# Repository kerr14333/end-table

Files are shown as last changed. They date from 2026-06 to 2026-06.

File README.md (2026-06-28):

# Cherry X-Leg End Table

A custom solid-cherry end table, designed parametrically in FreeCAD to sit beside
the leather armchair in `reference/chair.jpeg`.

**Overall: 20" L × 8¼" W × 24" H** — a thin floating top with a chamfered
underside edge over two crossed (X) tapered legs joined by half-laps, tied
together at the bottom by a central stretcher and at the top by two cleats (which
also attach the top with figure-8 fasteners for wood movement). Full dimensions and the build sequence are in
[`docs/plans.html`](docs/plans.html); the design brief is in
[`docs/END_TABLE_SPECS.md`](docs/END_TABLE_SPECS.md).

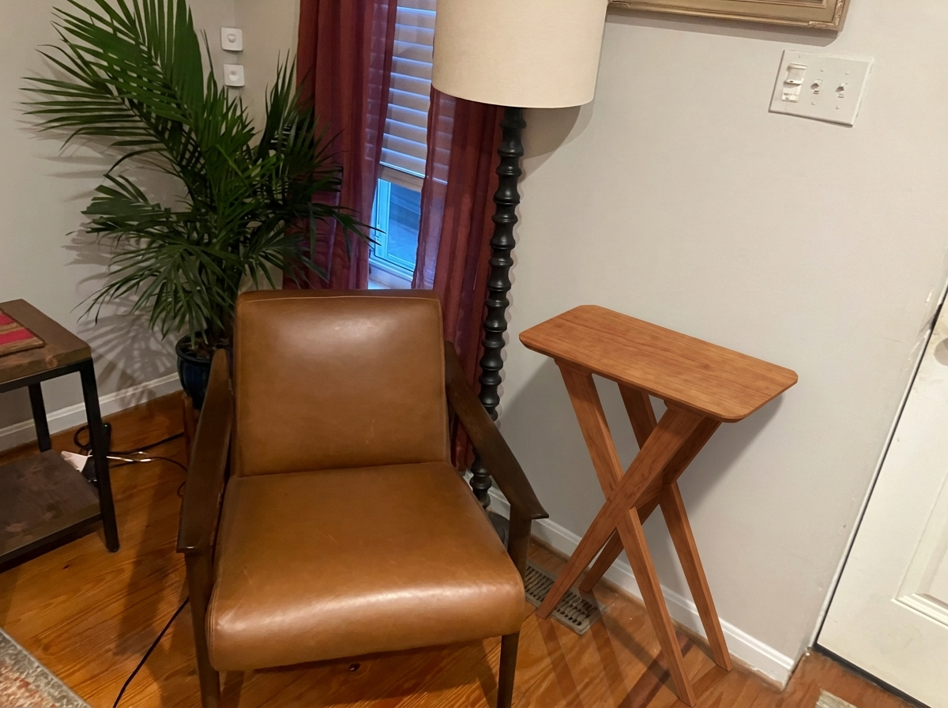
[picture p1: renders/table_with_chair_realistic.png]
Table beside the chair


## Project layout

```
end_table/
├── CLAUDE.md                 project instructions (build commands, layout)
├── README.md                 this file
├── docs/
│   ├── END_TABLE_SPECS.md    design brief / locked dimensions
│   ├── plans.html            printable build plans (cut list, joinery, steps)
│   └── diagrams/             generated SVG shop drawings (embedded in plans.html)
├── scripts/
│   ├── build_end_table.py    parametric model generator (FreeCAD)
│   ├── preview_end_table.py  orthographic CAD preview (matplotlib)
│   ├── draw_diagrams.py      dimensioned shop drawings (matplotlib → docs/diagrams)
│   └── gemini_render.py      photoreal render beside the chair (Gemini, on request)
├── model/                    generated CAD: end_table.FCStd (+ .stl mesh)
├── renders/                  generated images (previews + composite)
└── reference/                input assets: chair.jpeg
```

## Building the model

All commands run from the project root.

**1. Generate the CAD model** (writes `model/end_table.FCStd` + `.stl`):
```
"C:\Program Files\FreeCAD 1.1\bin\freecadcmd.exe" scripts\build_end_table.py
```
Edit the parameter block at the top of `scripts/build_end_table.py` to change any
dimension, then re-run.

**2. Render the CAD preview** (writes `renders/end_table_preview.png`):
```
python scripts\preview_end_table.py
```

**3. Generate the shop drawings** (writes dimensioned SVGs to `docs/diagrams/`,
embedded in `plans.html`):
```
python scripts\draw_diagrams.py
```

**4. Photoreal render beside the chair** (optional; writes
`renders/table_with_chair_realistic.png`):
```
python scripts\gemini_render.py
```
Requires `GEMINI_API_KEY` in the environment, `pip install google-genai`, and
billing enabled on the Google project.

## Requirements

- FreeCAD 1.1 (headless `freecadcmd`)
- Python 3 with `numpy`, `matplotlib`, `Pillow` (and `google-genai` for the
  Gemini render)

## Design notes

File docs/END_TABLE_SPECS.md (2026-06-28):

# End Table Spec

Material: 3/4" milled cherry. Build modeled in FreeCAD (see `build_end_table.py`).
Style: sleek modern / mid-century, to sit next to the chair in `images/chair.jpeg`
(warm wood, tapered splayed legs, eased edges, natural oil finish).

## Locked dimensions
* Overall: 24" tall.
* Top: 20" long x 8 1/4" wide x 3/4" thick. Width is fixed; length may be adjusted.
  * Corners rounded, 1 1/8" radius.
  * Underside perimeter: 45-deg routed chamfer 9/16" wide, leaving a 3/16" edge (reads thin / floats).
  * Top edge crisped with a 1/32" micro-bevel.
* Legs: two crossed (X) frames, 3/4" stock, tapered 2 1/2" wide at top to 1" at the foot.
  * Leg lean 30 deg from vertical (60 deg crossing angle). Chosen so the leg-end
    cuts (30 deg off square) and the half-lap nibble (90 - 2x30 = 30 deg off
    square) both fall on a positive stop of the miter gauge (POWERTEC 71391:
    every 5 deg to 60, plus 22.5). Tapers are done on a jig, so unconstrained.
  * Joined at each crossing with a half-lap, 3/8" deep.
  * Feet splayed past the tips (~15 7/8" stance) for stability; legs centered under the top.
  * End overhang ~4 1/2", side overhang ~1" (legs set wide for side-to-side stability).
* One central stretcher ties the two frames together at the crossing. It is glued
  and dowelled into each frame's inner face — two 3/8" dowels per end (its end
  grain needs the dowels; glue alone there is weak).
* Two cleats (~7 x 3 5/8 x 3/4) under the ends of the top: sized and centered on
  the angled leg-tip footprint so each leg seats squarely (the trimmed tips land
  slightly inboard of the leg's nominal tip). The two long bottom edges are eased
  with a 1/4" 45-deg bevel so the cleats read lighter (ends left square, where the
  leg tips bear). The leg tips bear on them, they tie the two frames together at
  the top, and the top fastens to them with figure-8 (desktop) fasteners — two per
  cleat, recessed flush into the cleat top, which pivot to allow seasonal wood movement.

## Tools on hand
Tablesaw, router, miter saw, and standard hand tools.

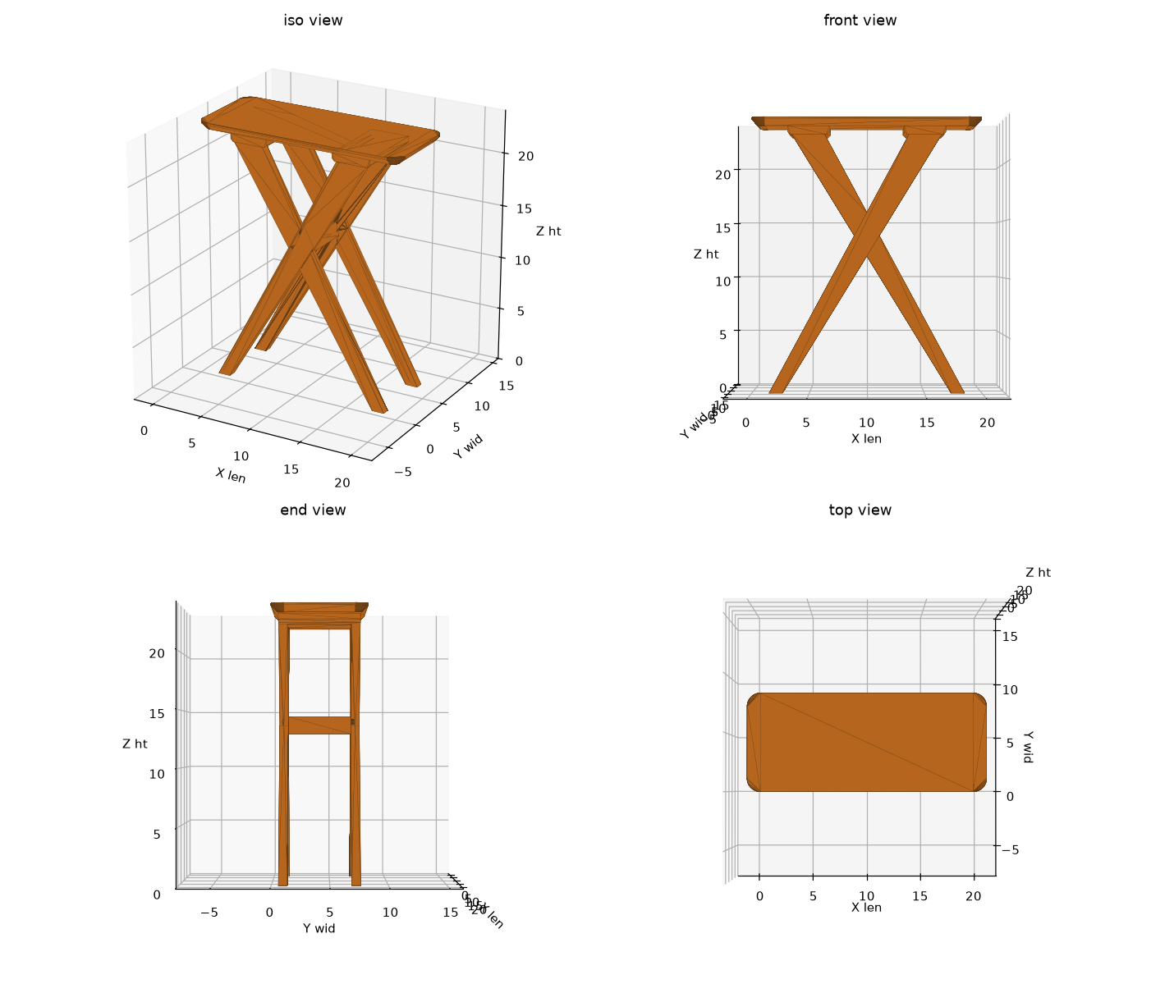
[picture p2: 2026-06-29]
renders/end_table_preview.png

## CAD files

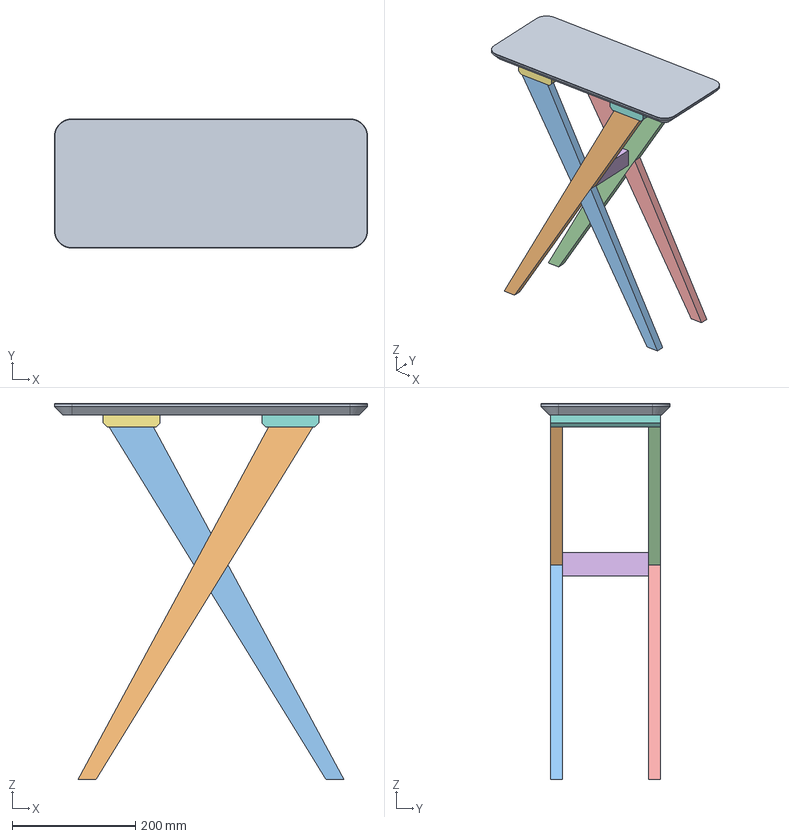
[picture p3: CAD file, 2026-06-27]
model/end_table.FCStd
508.0 x 209.6 x 609.6 mm
Top
Frame1_LegFwd
Frame1_LegBack
Frame2_LegFwd
Frame2_LegBack
Stretcher
Cleat_End1
Cleat_End2
Dowel_A1
Dowel_A2
Dowel_B1
Dowel_B2

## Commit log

2026-06-27 Initial commit: parametric cherry X-leg end table
    FreeCAD parametric model plus CAD/photoreal render scripts, printable build
    plans, and the design spec, organized into docs/ scripts/ model/ renders/
    reference/. Scripts resolve paths relative to the project root.
    [end_table.FCStd]
2026-06-27 Add top cleats, widen stance for stability, document leg machining
    - Model: two end cleats under the top (leg tips bear on them; slotted screws up
    into the top for wood movement) tying the frames together at the top; legs now
    stop 3/4" below the top. Widened the side stance (side overhang 1.5" -> 1") to
    roughly double side-to-side tip resistance while keeping the bevel and end
    overhang.
    - Plans: new Leg Machining section (miter-gauge end angles, taper, scribed
    half-lap); refreshed cut list, dimensions, stability note, and assembly steps.
    - Specs/README updated to match.
    [end_table.FCStd]
2026-06-27 Align cleats to actual angled leg-tip footprint
    The cleats were sized/centered on the legs' nominal tip X (TIP_L/TIP_R at
    the full tip height), but each leg is a diagonal board trimmed flat 3/4"
    below its true tip. Its top therefore lands ~0.4" inboard and spans a wide
    ~2.8" diagonal footprint, so the leg seated off-center on the 3" cleat.
    Derive each cleat's X position/width from the leg's real top footprint
    (sliced at the trim height) plus a uniform 3/8" reveal each side, so the
    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
    [end_table.FCStd]
2026-06-27 Add dimensioned shop drawings to the build plans
    New scripts/draw_diagrams.py generates four dimensioned SVG drawings from the
    same parameters as the model: side elevation (heights, foot stance, leg and
    crossing angles), end elevation (width, frame spacing, stretcher), leg detail
    (taper, 28-deg end cut, half-lap), and top plan (corner radius, cleat
    placement). Embedded in docs/plans.html as a new "Shop Drawings" section.
    SVGs are tracked as part of the plans; the verification PNGs are gitignored.
2026-06-27 Modernize proportions (thinner top, finer legs, slimmer stretcher, crisp edge)
    Subtle refinements that keep the design, footprint, joinery, and stability:
    - Top reads thinner: edge reveal 1/4" -> 3/16" (chamfer deepened to 9/16").
    - Sleeker legs: taper to a 1" foot (was 1-1/4"); feet positions unchanged so
    the 14" stance and tip resistance are the same.
    - Slimmer central stretcher: 1-1/2" tall (was 2-1/2").
    - Crisper top edge: 1/32" micro-bevel (chamfer) instead of a 1/8" roundover.
    Rebuilt model + diagrams; specs and plans updated to match.
    [end_table.FCStd]
2026-06-27 Bevel cleat bottom edges so they read more subtly
    Add a 1/4" 45-deg chamfer to each cleat's two long bottom edges (CLEAT_BEVEL),
    so the cleats look lighter under the top. Only the long (Y-running) bottom edges
    are beveled and CLEAT_BEVEL < CLEAT_MARGIN, so the full leg-tip footprint still
    bears on flat stock; the ends stay square because the leg tips land at the very
    ends of each cleat.
    Diagrams (side + end elevation) and docs updated to show/note the bevel.
    [end_table.FCStd]
2026-06-27 Dowel the stretcher to the frames (model + plans)
    The stretcher butts end-grain against each frame's inner face, so glue alone is
    weak. Specify and model glued + dowelled joints: two 3/8" x 1-1/4" dowels per
    end (4 total), ~1/2" into the leg face and ~3/4" into the stretcher end.
    - build_end_table.py: model the 4 dowels and drill the matching holes (boolean
    cut) in the stretcher and the frame legs so the pins seat with no overlap.
    Also fix stale A_inner/B_inner comments (1.375 / 6.875).
    - draw_diagrams.py: show the hidden dowels (dashed) in the end elevation.
    - plans.html / END_TABLE_SPECS.md: dowel spec in the cut list, a new
    "Stretcher joint (dowels)" joinery panel, and the assembly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
    [end_table.FCStd]
2026-06-27 Set leg lean to 30 deg so all miter-gauge cuts land on a positive stop
    The user's miter gauge (POWERTEC 71391) only indexes at positive stops: every
    5 deg to 60, plus 22.5. The old 28.3 deg lean put the half-lap nibble at ~33.5
    deg off square -- not a stop. Drive the geometry from LEAN_DEG and set it to 30:
    - leg-end cuts = 30 deg off square (stop)
    - half-lap nibble = 90 - 2*30 = 30 deg off square (stop)
    - crossing angle = 60 deg; stance widens to ~15-7/8" (a bit more stable)
    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
    [end_table.FCStd]
2026-06-27 Fix end-elevation diagram: cleat ends are square, not beveled
    The cleat bevel is only on its long (length-facing) edges, so end-on it reads as
    a plain rectangle with square ends and the legs sit flush. The diagram wrongly
    applied the corner-bevel to the cleat ends, making the legs look like they
    overhang the cleat. Model was always correct -- drawing only.
2026-06-28 Add table-saw leg instructions, all diagram angles, and figure-8 top fasteners
    - Rewrite leg machining as a table-saw-only, step-by-step procedure with a
    full angle/dimension table; account for the Bosch 4100 jobsite saw (miter
    saw for the 30-deg end cuts; router or single-blade nibble for the half-lap
    since the 4100 takes no dado stack).
    - Annotate every build angle on the shop drawings: 30-deg off-square end cuts,
    30-deg half-lap nibble, taper ~3.3 deg, 30-deg-off-vertical and 60-deg
    crossing, 45-deg cleat/underside chamfers. Show the blank vs. real 30-deg
    cut, hatch the waste, and label the finished ~58-62-deg corner points.
    - Fix leg-detail end-cut indicator (offset now width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
2026-06-30 Reflect tapered-leg splay in the half-lap detail and plans
    The legs are tapered, so each leg's two long edges aren't parallel
    (they splay ~3.3 deg). That makes the half-lap notch walls non-parallel
    too -- they sit at 30 deg +/- ~1.7 deg off square, not a single 30 deg.
    - leg_detail diagram: draw the two notch walls splayed (exaggerated),
    put the ~30 deg "off square" arc on the notch centerline (the true
    nominal), and call out that the walls splay with the taper and must
    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
2026-06-30 Dimension the half-lap: foot-to-lap distance on each leg edge
    Because the lap is skewed (60 deg crossing) and the board is tapered,
    each of the two lap shoulder lines meets the leg's two edges at a
    different distance from the foot. Add those real measurements.
    - leg_detail diagram: replace the schematic notch with the true notch,
    computed from where the mating leg's edges cross this leg's edges, and
    dimension foot->each lap line along each edge: top edge 15-9/16" and
    17-7/8", bottom edge 14" and 16-1/16".
    - plans.html: add the same four numbers to the scribe step as a
    cross-check (not a substitute for scribing).
